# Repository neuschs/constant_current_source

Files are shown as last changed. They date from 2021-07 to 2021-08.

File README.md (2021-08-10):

# Constant Current Source
"Precise" Constant Current Source based on TI XTR110AG

# Main Components 

## Revision 0.1
### Arduino Nano
Simple Arduino for processing of the SCPI commands and coordinating the range switching.
### MCP3202
Two channel SPI 12 Bit ADC with external reference voltage.
### REF02
Reference voltage source used for internal "calibration" and as reference for arduino ADC and MCP3202

# Measurments
## Revision 0.1
### Stability over 2 Hours
Measured against reference voltage source REF02

#### Parameters:
- Duration: 2 Hours
- Frequency: 1s (approx.)
- Attentuatuation before LM324N: 8 (rough setting)
- LSB at ADC: approx 9,765mV (with Attentuation of 8)
- Internal Averaging Samples: 50

### Voltage A (Sense A):
| Value | Measurment |
| ---| --- |
|Standard Deviation| 1,456 mV |
|Maximum Value| 5.216500 V  |
|Minimum Value| 5.207500 V  |
|Mean Value| 5.213059 V  |
|25% of Counts| 5.212000 V  |
|50% of Coutns| 5.213200 V  |
|75% of Counts| 5.214200 V  |

### Boxplot and Histogram
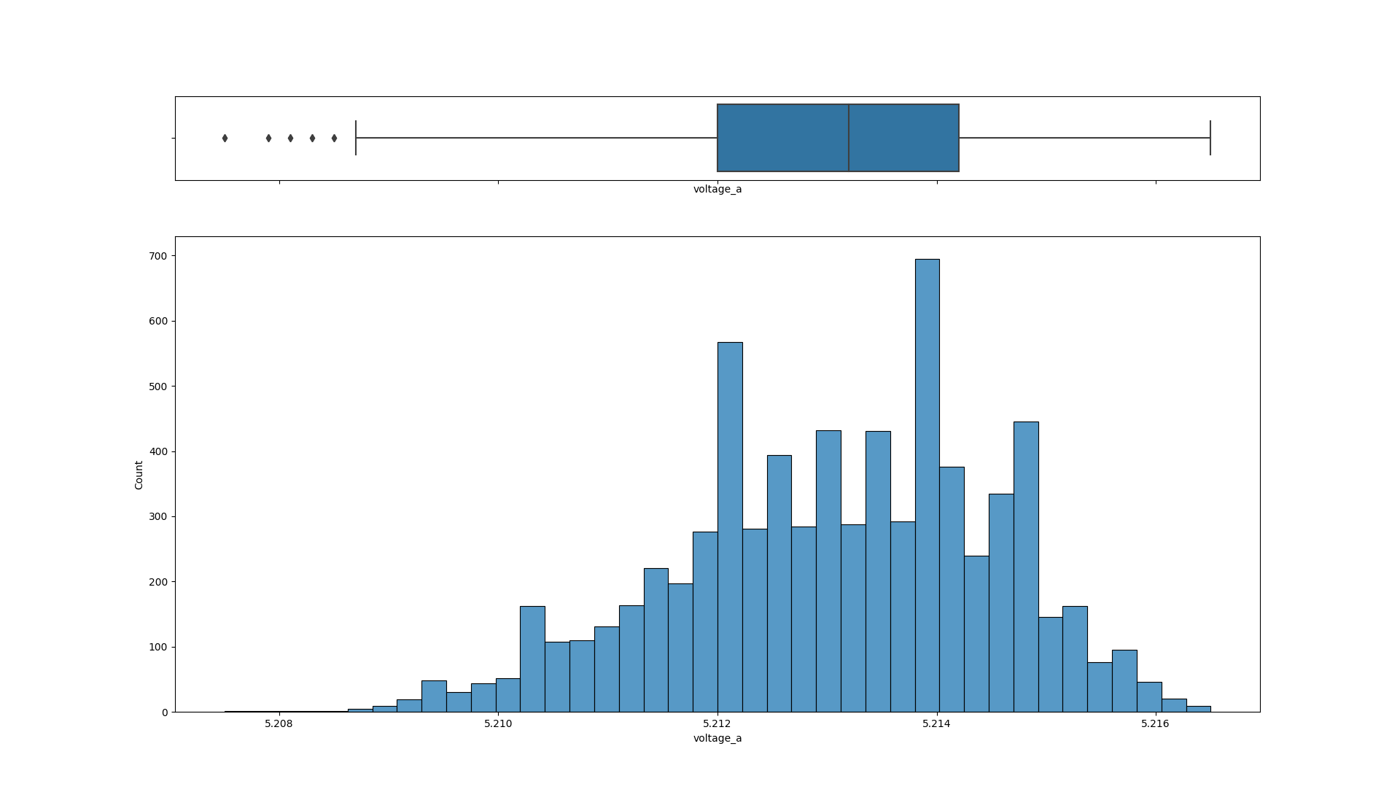
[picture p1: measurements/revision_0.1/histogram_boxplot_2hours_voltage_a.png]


### Voltage B (Sense B):
| Value | Measurment |
| ---| ---  |
|Standard Deviation| 411 uV |
|Maximum Value: |  5.150300 V  |
|Minimum Value: |  5.146000 V  |
|Mean Value: |  5.147937 V  |
|25% of Counts: |  5.147700 V  |
|50% of Coutns: |  5.147900 V  |
|75% of Counts: |  5.148100 V  |

### Boxplot and Histogram
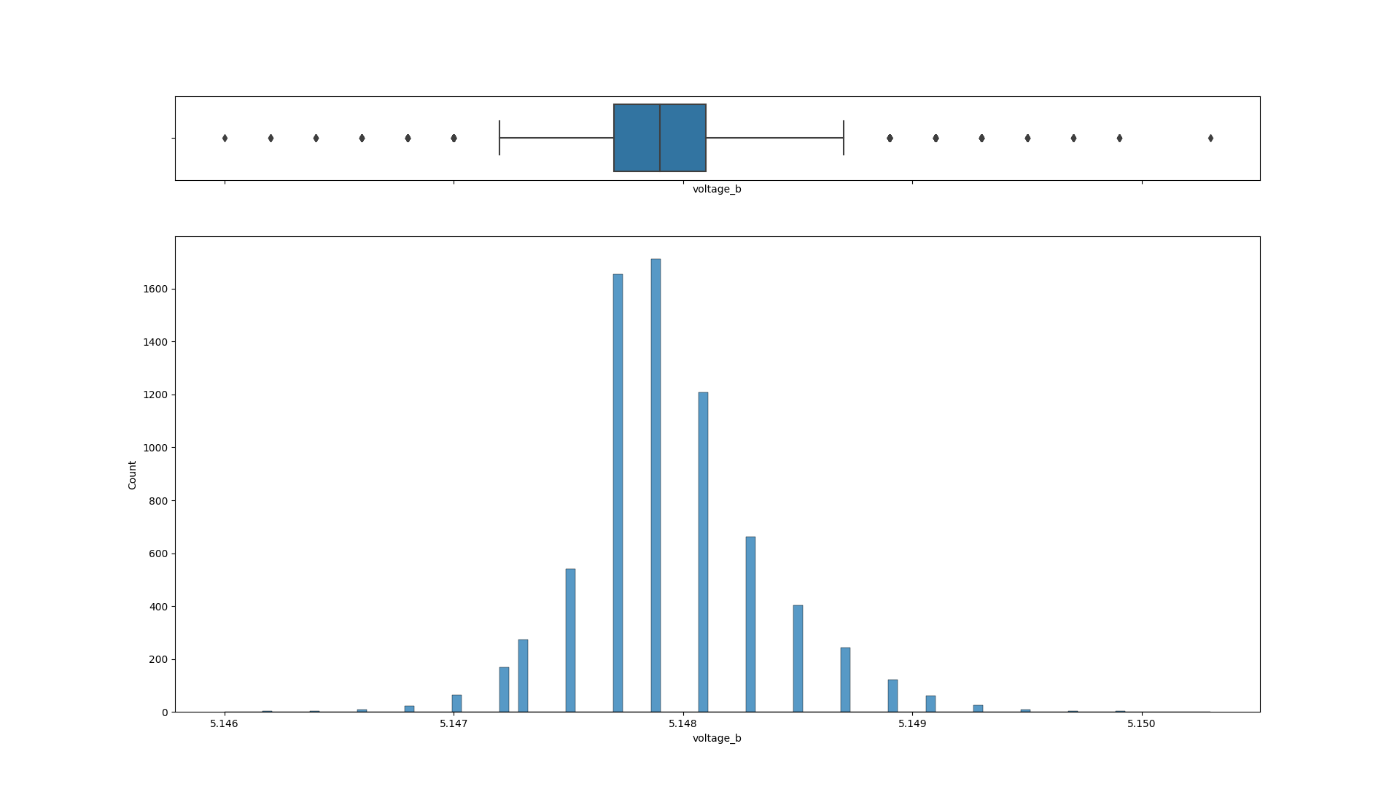
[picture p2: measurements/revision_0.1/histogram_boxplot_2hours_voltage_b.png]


### Overview over 2 Hours
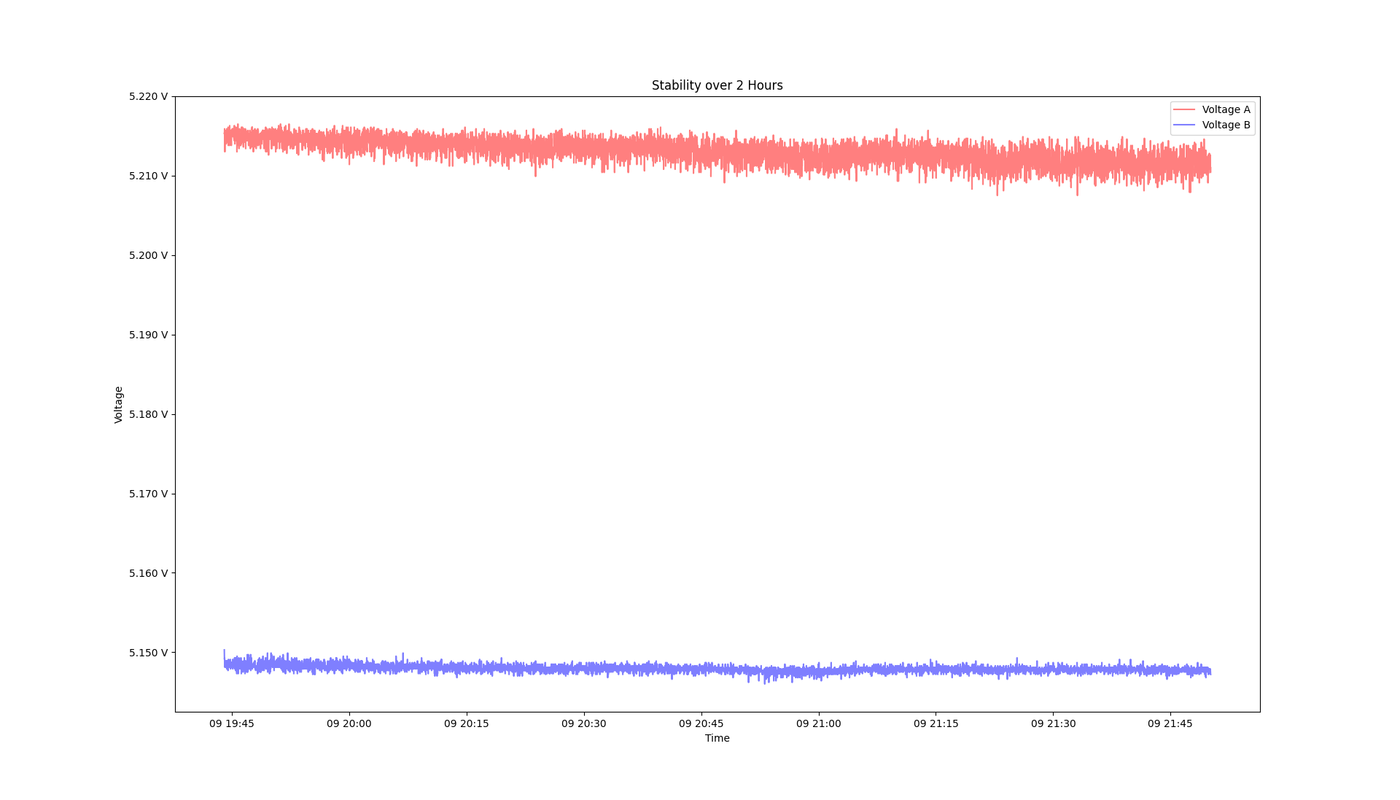
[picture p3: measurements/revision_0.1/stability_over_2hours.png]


### Result
> In some mysterious way, Sense A voltage measrument is way more bad than Sense B. Next measurment will be done over 24h with better shielding against the USB connection which is directly over the input attentuation voltage divider.

# Credits
Used Librarys:

[vrekrer/Vrekrer SCPI parser@0.4.1](https://github.com/Vrekrer/Vrekrer_scpi_parser)

[robtillaart/PCF8574@0.3.2](https://github.com/RobTillaart/PCF8574)

[mokolea/InputDebounce@1.6.0](https://github.com/Mokolea/InputDebounce)

[ouviksaha97/MCP3202@1.0.2](https://github.com/souviksaha97/MCP3202)

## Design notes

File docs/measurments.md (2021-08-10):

layout: page
title: "Measurments"
permalink: /measurments/

# Measurments
## Revision 0.1
### Stability over 2 Hours
Measured against reference voltage source REF02

#### Parameters:
- Duration: 2 Hours
- Frequency: 1s (approx.)
- Attentuatuation before LM324N: 8 (rough setting)
- LSB at ADC: approx 9,765mV (with Attentuation of 8)
- Internal Averaging Samples: 50

### Voltage A (Sense A):
| Value | Measurment |
| ---| --- |
|Standard Deviation| 1,456 mV |
|Maximum Value| 5.216500 V  |
|Minimum Value| 5.207500 V  |
|Mean Value| 5.213059 V  |
|25% of Counts| 5.212000 V  |
|50% of Coutns| 5.213200 V  |
|75% of Counts| 5.214200 V  |

### Boxplot and Histogram
![PIC][https://github.com/neuschs/constant_current_source/measurements/revision_0.1/histogram_boxplot_2hours_voltage_a.png]

### Voltage B (Sense B):
| Value | Measurment |
| ---| ---  |
|Standard Deviation| 411 uV |
|Maximum Value: |  5.150300 V  |
|Minimum Value: |  5.146000 V  |
|Mean Value: |  5.147937 V  |
|25% of Counts: |  5.147700 V  |
|50% of Coutns: |  5.147900 V  |
|75% of Counts: |  5.148100 V  |

### Boxplot and Histogram
hi

### Overview over 2 Hours
hi

### Result
> In some mysterious way, Sense A voltage measrument is way more bad than Sense B. Next measurment will be done over 24h with better shielding against the USB connection which is directly over the input attentuation voltage divider.

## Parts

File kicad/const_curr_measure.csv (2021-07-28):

ID | Bezeichner | Gehäuse | Stückzahl | Bezeichnung | Anbieter und Referenz
1 | J13 | PinHeader_1x05_P2.54mm_Vertical | 1 | Conn_01x05
2 | J5,J7 | PinHeader_1x03_P2.54mm_Vertical | 2 | Conn_01x03
3 | J3 | PinHeader_1x12_P2.54mm_Vertical | 1 | Conn_01x12
4 | U2 | DIP-8_W7.62mm_LongPads | 1 | MCP4821
5 | TP38,TP37,TP36,TP34,TP33,TP26,TP16,TP5,TP4,TP1,TP35,TP2,TP32,TP31,TP30,TP29,TP28,TP27,TP25,TP24,TP23,TP22,TP21,TP20,TP19,TP18,TP17,TP15,TP14,TP13,TP12,TP11,TP10,TP9,TP8,TP7,TP6,TP3 | TestPoint_THTPad_D2.5mm_Drill1.2mm | 38 | 1018.68
6 | U4 | DIP-8_W7.62mm_LongPads | 1 | MCP3202
7 | U3 | DIP-8_W7.62mm_LongPads | 1 | REF02CP
8 | RV1,R13,R4,R3 | Potentiometer_Piher_PT-6-V_Vertical | 4 | 10k
9 | C10,C8,C7,C6,C5,C2,C1 | C_Rect_L7.2mm_W3.0mm_P5.00mm_FKS2_FKP2_MKS2_MKP2 | 7 | 100nF
10 | R20 | R_Axial_DIN0207_L6.3mm_D2.5mm_P10.16mm_Horizontal | 1 | 4k7
11 | R19,R18,R10,R9 | R_Axial_DIN0207_L6.3mm_D2.5mm_P10.16mm_Horizontal | 4 | R
12 | R8,R12,R2 | R_Axial_DIN0207_L6.3mm_D2.5mm_P10.16mm_Horizontal | 3 | 10k
13 | D4,D3,D2,D1 | D_A-405_P10.16mm_Horizontal | 4 | D_Schottky
14 | A1 | Arduino_Nano | 1 | Arduino_Nano_v3.x
15 | J6,J8,J4,J2,J10,J9,J11 | 17263862 | 7 | 1-726386-2
16 | R7 | R_Axial_DIN0207_L6.3mm_D2.5mm_P10.16mm_Horizontal | 1 | 10
17 | R6 | R_Axial_DIN0207_L6.3mm_D2.5mm_P10.16mm_Horizontal | 1 | 1
18 | C4 | C_Rect_L7.2mm_W3.0mm_P5.00mm_FKS2_FKP2_MKS2_MKP2 | 1 | 1uF Tantal
19 | C3 | C_Rect_L7.2mm_W3.0mm_P5.00mm_FKS2_FKP2_MKS2_MKP2 | 1 | 10uF Tantal
20 | K4,K3,K1,K2 | 36SERIES-MINIATURE-PCB-RELAYS-10A | 4 | 36.11.9.005.4011
21 | R15,R5 | Potentiometer_Piher_PT-6-V_Vertical | 2 | 1k
22 | R14 | Potentiometer_Piher_PT-6-V_Vertical | 1 | 47k
23 | U6 | DIP-16_W7.62mm_LongPads | 1 | ULN2003
24 | H4,H3,H2,H1 | 638231 | 4 | 63823-1
25 | J12 | 09061152911_2 | 1 | 09061152911
26 | IC1 | CDIP774W53P254L2057H445Q16 | 1 | XTR110AG
27 | R17,R1,R11 | R_Axial_DIN0207_L6.3mm_D2.5mm_P10.16mm_Horizontal | 3 | 100k
28 | R16 | R_Axial_DIN0207_L6.3mm_D2.5mm_P10.16mm_Horizontal | 1 | 82k
29 | C9 | C_Disc_D5.0mm_W2.5mm_P5.00mm | 1 | 100nF
30 | U5 | DIP-16_W7.62mm_LongPads | 1 | PCF8574
31 | U1 | DIP-14_W7.62mm_LongPads | 1 | LM324
32 | J1 | PinHeader_2x02_P2.54mm_Vertical | 1 | Conn_02x02_Counter_Clockwise

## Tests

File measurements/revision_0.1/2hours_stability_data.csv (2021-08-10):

time | voltage_a | voltage_b
2021-08-09 19:44:02.686931 | 5.2153 | 5.1503
2021-08-09 19:44:03.738297 | 5.2153 | 5.1491
2021-08-09 19:44:04.789710 | 5.2159 | 5.1493
2021-08-09 19:44:05.840950 | 5.2151 | 5.1489
2021-08-09 19:44:06.892429 | 5.213 | 5.1481
2021-08-09 19:44:07.944663 | 5.2157 | 5.1485
2021-08-09 19:44:08.996051 | 5.2142 | 5.1487
2021-08-09 19:44:10.047480 | 5.2144 | 5.1489
2021-08-09 19:44:11.098875 | 5.2147 | 5.1483
2021-08-09 19:44:12.151008 | 5.2153 | 5.1481
2021-08-09 19:44:13.202452 | 5.2153 | 5.1489
2021-08-09 19:44:14.253629 | 5.2147 | 5.1487
2021-08-09 19:44:15.305876 | 5.2157 | 5.1481
2021-08-09 19:44:16.357240 | 5.2146 | 5.1485
2021-08-09 19:44:17.408811 | 5.214 | 5.1483
2021-08-09 19:44:18.460804 | 5.2149 | 5.1483
2021-08-09 19:44:19.512178 | 5.2155 | 5.1489
2021-08-09 19:44:20.563529 | 5.2151 | 5.1483
2021-08-09 19:44:21.615037 | 5.2159 | 5.1479
2021-08-09 19:44:22.667254 | 5.2153 | 5.1489
2021-08-09 19:44:23.718610 | 5.2146 | 5.1485
2021-08-09 19:44:24.747614 | 5.2157 | 5.1485
2021-08-09 19:44:25.798987 | 5.2149 | 5.1483
2021-08-09 19:44:26.850393 | 5.2153 | 5.1479
2021-08-09 19:44:27.902583 | 5.2144 | 5.1489
2021-08-09 19:44:28.953960 | 5.2142 | 5.1485
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

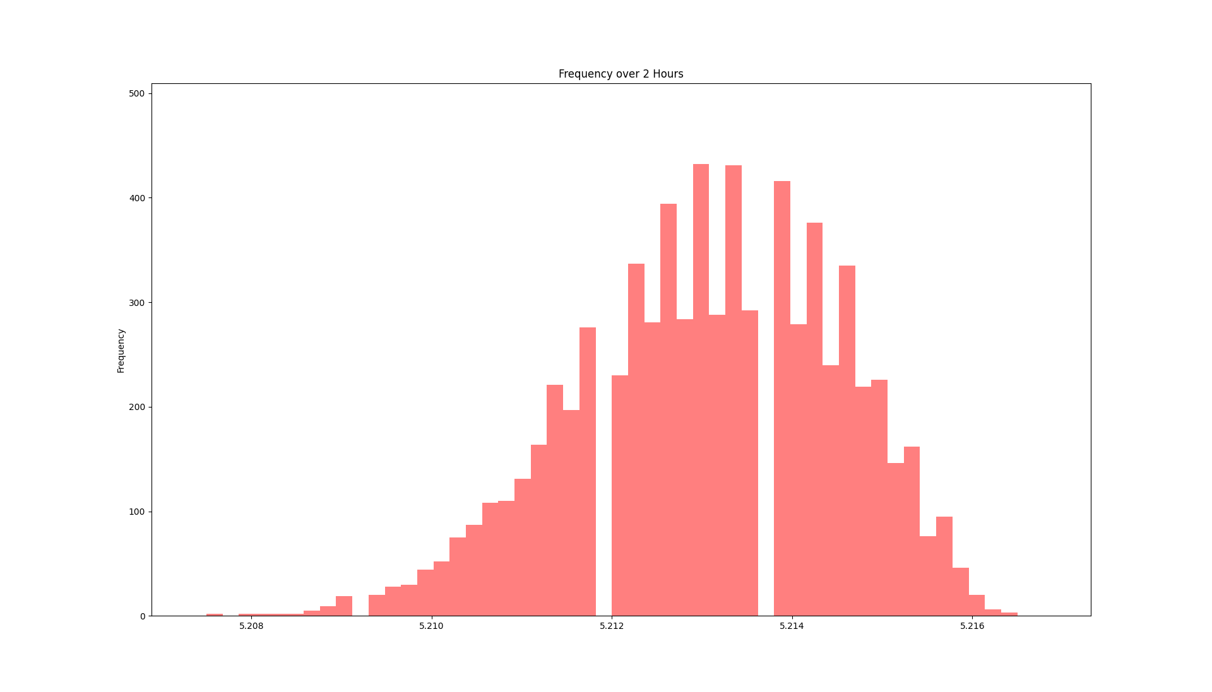
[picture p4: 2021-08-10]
measurements/revision_0.1/frequeny_2hours_voltage_a.png

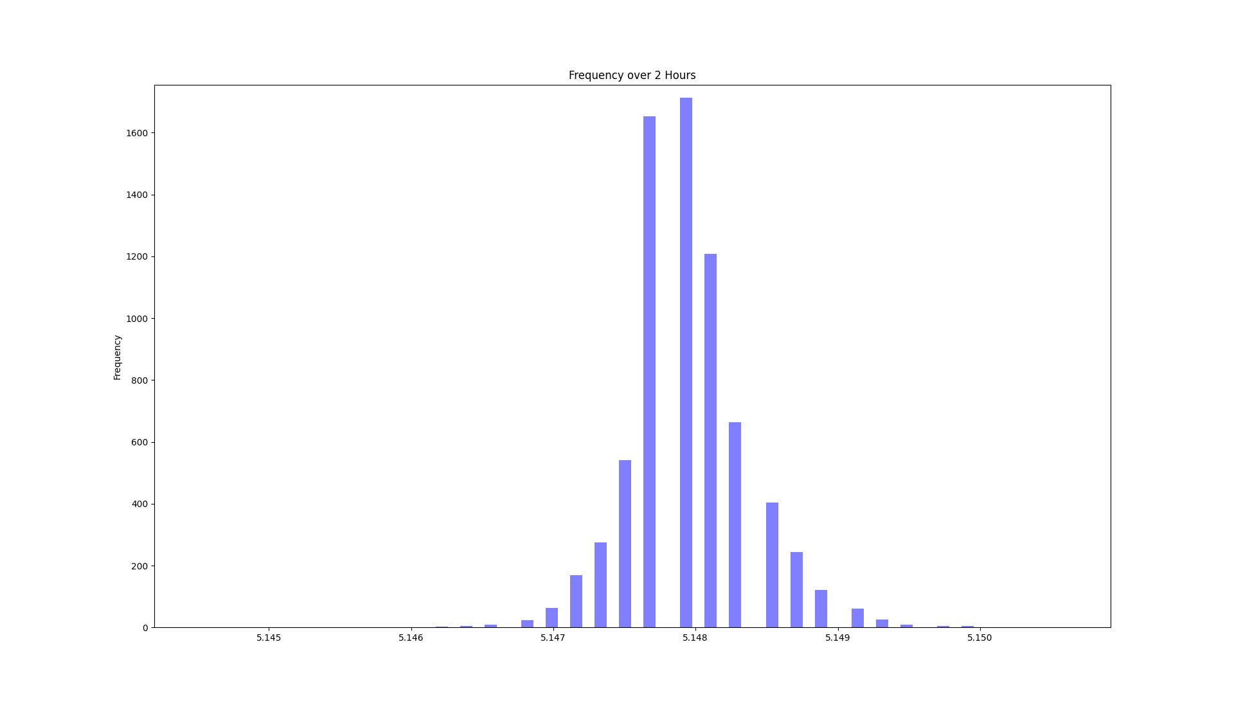
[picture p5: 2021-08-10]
measurements/revision_0.1/frequeny_2hours_voltage_b.png

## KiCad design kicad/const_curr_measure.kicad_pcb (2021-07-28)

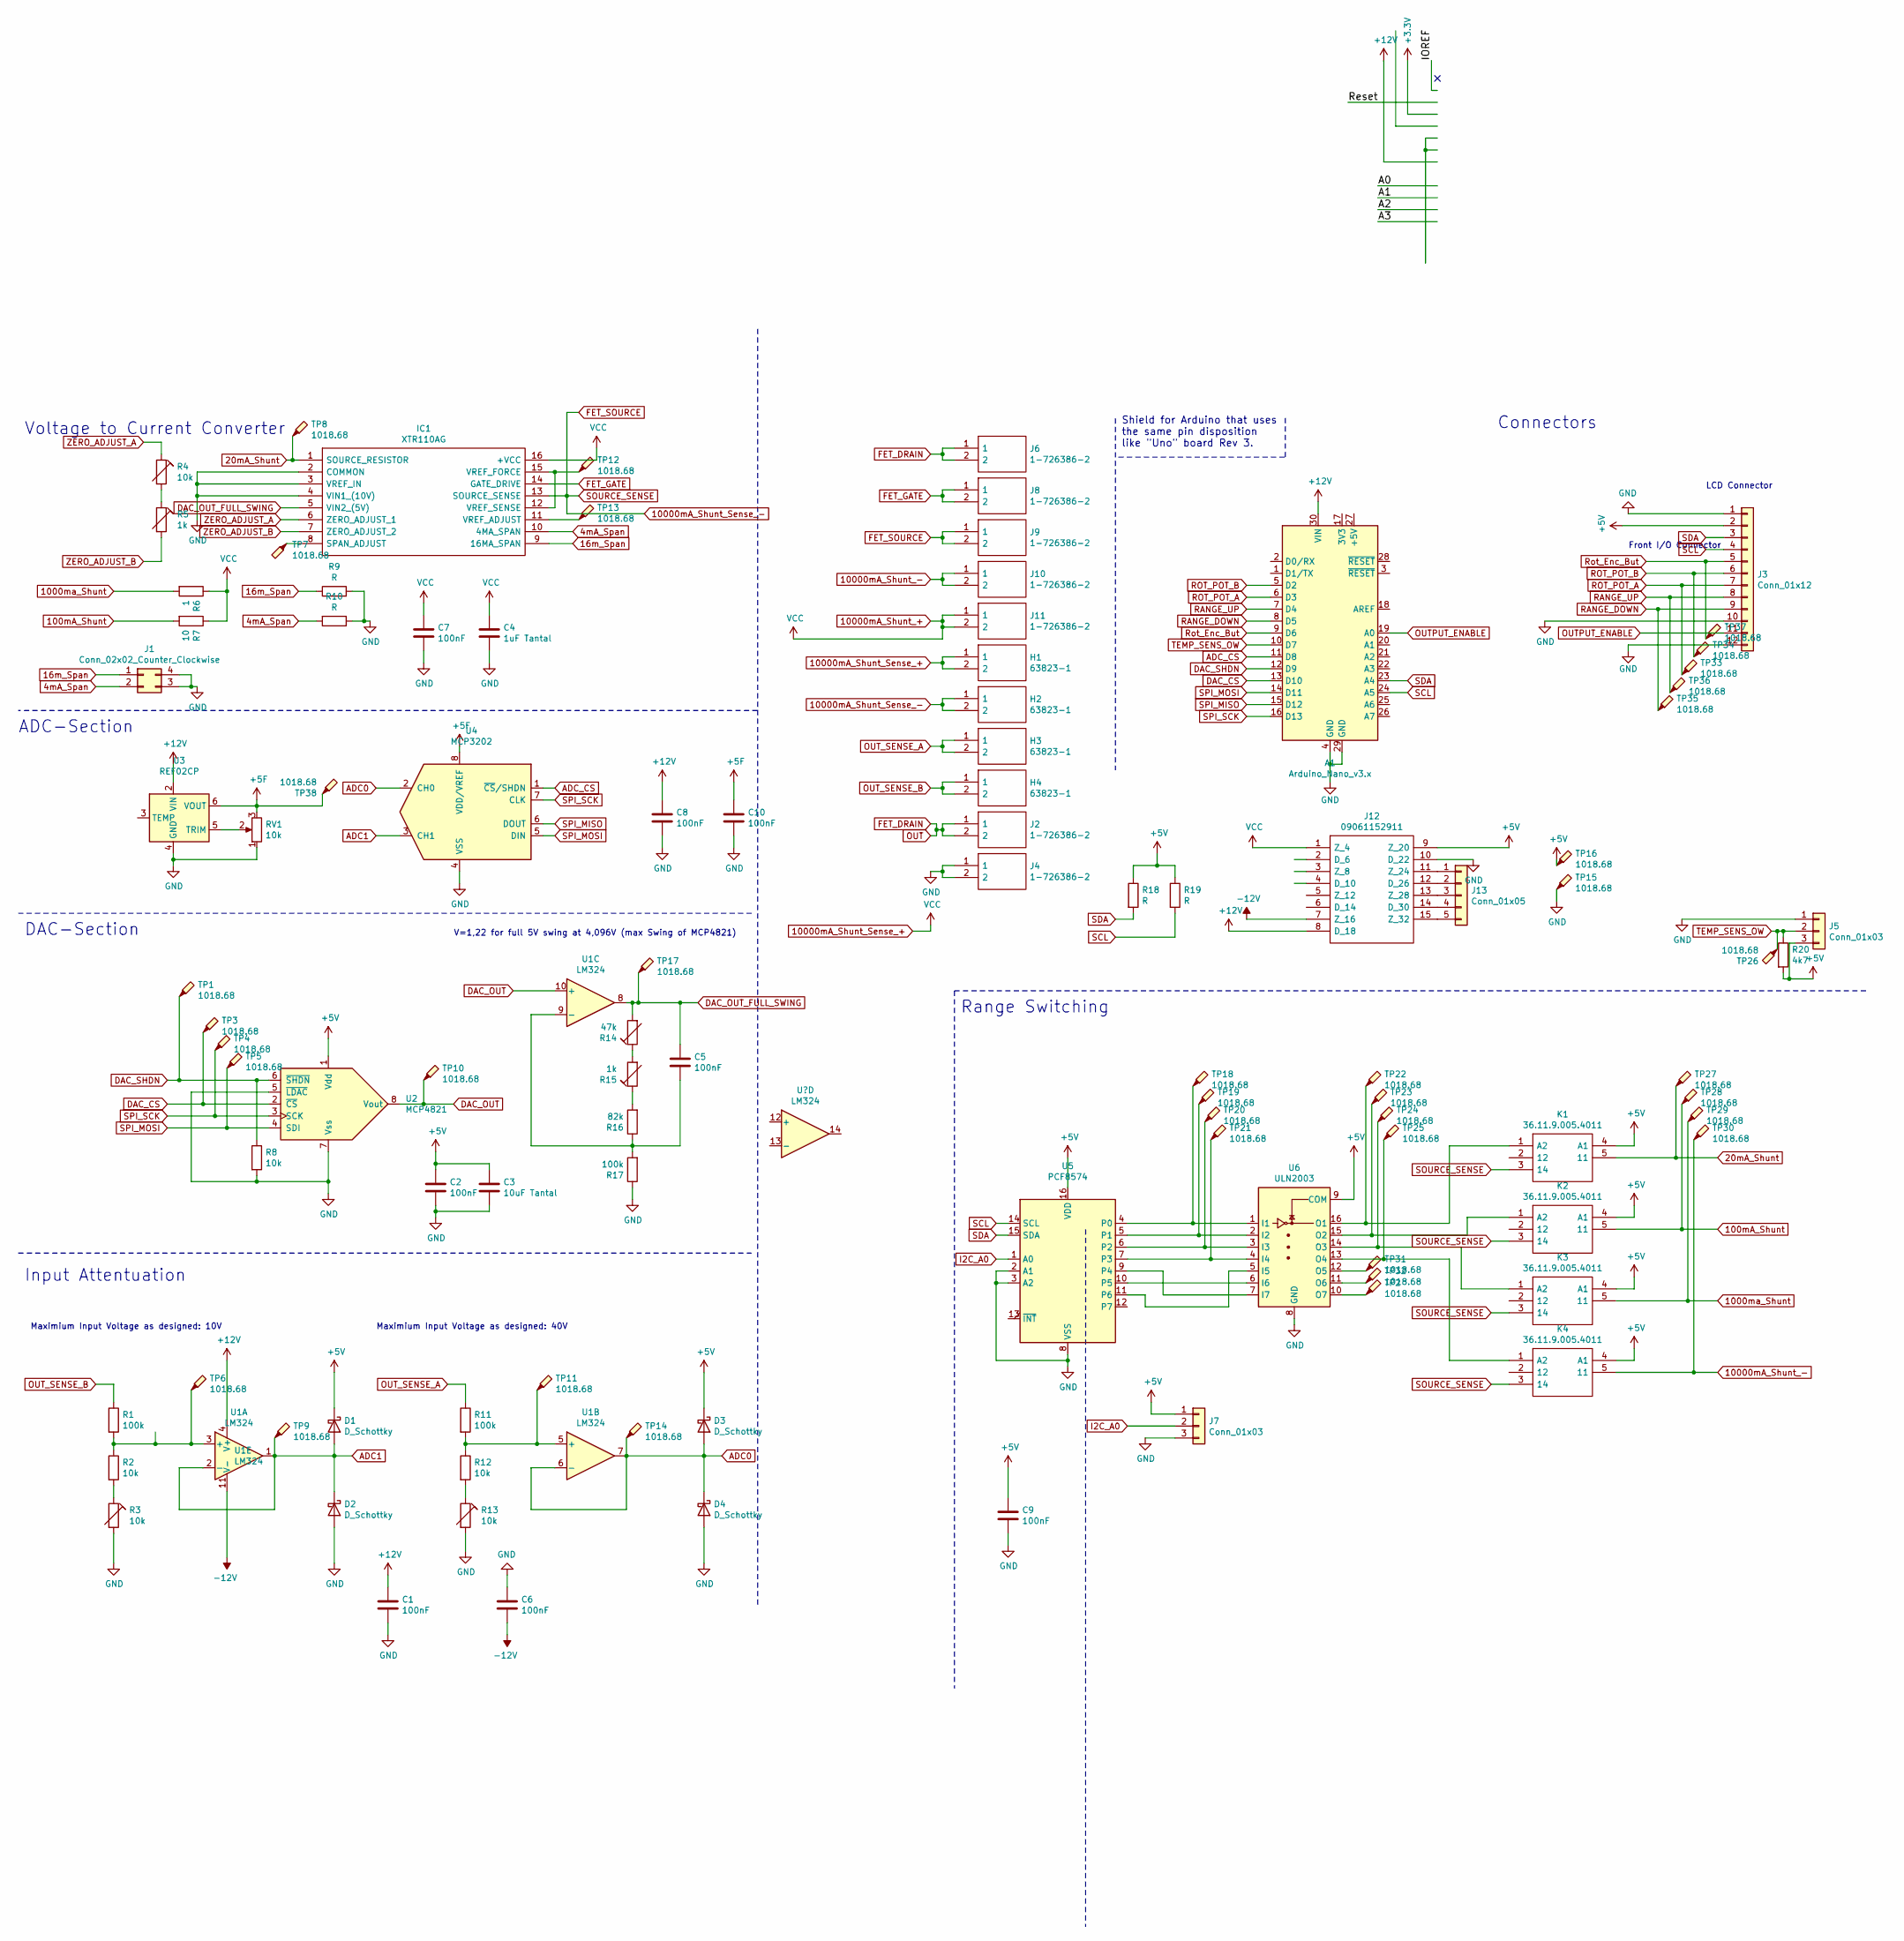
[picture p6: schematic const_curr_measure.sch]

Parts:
A1: Arduino_Nano_v3.x; Arduino_Nano
C1, C2, C5, C6, C7, C8, C10: 100nF; C_Rect_L7.2mm_W3.0mm_P5.00mm_FKS2_FKP2_MKS2_MKP2
C3: 10uF Tantal; C_Rect_L7.2mm_W3.0mm_P5.00mm_FKS2_FKP2_MKS2_MKP2
C4: 1uF Tantal; C_Rect_L7.2mm_W3.0mm_P5.00mm_FKS2_FKP2_MKS2_MKP2
C9: 100nF; C_Disc_D5.0mm_W2.5mm_P5.00mm
D1, D2, D3, D4: D_Schottky; D_A-405_P10.16mm_Horizontal
H1, H2, H3, H4: 63823-1; 638231; Mouser Part Number 571-638231
IC1: XTR110AG; CDIP774W53P254L2057H445Q16; Mouser Part Number 595-XTR110AG
J1: Conn_02x02_Counter_Clockwise; PinHeader_2x02_P2.54mm_Vertical
J2, J4, J6, J8, J9, J10, J11: 1-726386-2; 17263862; Mouser Part Number 571-1-726386-2
J3: Conn_01x12; PinHeader_1x12_P2.54mm_Vertical
J5, J7: Conn_01x03; PinHeader_1x03_P2.54mm_Vertical
J12: 09061152911; 09061152911_2; Manufacturer_Part_Number 09061152911; Mouser Part Number 617-09-06-115-2911
J13: Conn_01x05; PinHeader_1x05_P2.54mm_Vertical
K1, K2, K3, K4: 36.11.9.005.4011; 36SERIES-MINIATURE-PCB-RELAYS-10A; Manufacturer_Part_Number 36.11.9.005.4011
R1, R11, R17: 100k; R_Axial_DIN0207_L6.3mm_D2.5mm_P10.16mm_Horizontal
R2, R8, R12: 10k; R_Axial_DIN0207_L6.3mm_D2.5mm_P10.16mm_Horizontal
R3, R4, R13: 10k; Potentiometer_Piher_PT-6-V_Vertical
R5, R15: 1k; Potentiometer_Piher_PT-6-V_Vertical
R6: 1; R_Axial_DIN0207_L6.3mm_D2.5mm_P10.16mm_Horizontal
R7: 10; R_Axial_DIN0207_L6.3mm_D2.5mm_P10.16mm_Horizontal
R9, R10, R18, R19: R; R_Axial_DIN0207_L6.3mm_D2.5mm_P10.16mm_Horizontal
R14: 47k; Potentiometer_Piher_PT-6-V_Vertical
R16: 82k; R_Axial_DIN0207_L6.3mm_D2.5mm_P10.16mm_Horizontal
R20: 4k7; R_Axial_DIN0207_L6.3mm_D2.5mm_P10.16mm_Horizontal
RV1: 10k; Potentiometer_Piher_PT-6-V_Vertical
TP1, TP2, TP3, TP4, TP5, TP6, TP7, TP8, TP9, TP10, TP11, TP12, TP13, TP14, TP15, TP16, TP17, TP18, TP19, TP20, TP21, TP22, TP23, TP24, TP25, TP26, TP27, TP28, TP29, TP30, TP31, TP32, TP33, TP34, TP35, TP36, TP37, TP38: 1018.68; TestPoint_THTPad_D2.5mm_Drill1.2mm
U1: LM324; DIP-14_W7.62mm_LongPads
U2: MCP4821; DIP-8_W7.62mm_LongPads
U3: REF02CP; DIP-8_W7.62mm_LongPads
U4: MCP3202; DIP-8_W7.62mm_LongPads
U5: PCF8574; DIP-16_W7.62mm_LongPads
U6: ULN2003; DIP-16_W7.62mm_LongPads

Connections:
4mA_Span: IC1.10 (4MA_SPAN), J1.2, R10.2
16m_Span: IC1.9 (16MA_SPAN), J1.1, R9.1
20mA_Shunt: IC1.1 (SOURCE_RESISTOR), K1.5 (11), TP8.1, TP27.1
100mA_Shunt: K2.5 (11), R7.2, TP28.1
1000ma_Shunt: K3.5 (11), R6.2, TP29.1
10000mA_Shunt_+: C4.1, C7.1, H1.1, H1.2, IC1.16 (+VCC), J11.1, J11.2, J12.1 (Z_4), R6.1, R7.1
10000mA_Shunt_-: J10.1, J10.2, K4.5 (11), TP30.1
10000mA_Shunt_Sense_-: H2.1, H2.2, IC1.13 (SOURCE_SENSE), J9.1, J9.2, K1.3 (14), K2.3 (14), K3.3 (14), K4.3 (14)
+5F: C10.1, RV1.3, TP38.1, U3.6 (VOUT), U4.8 (VDD/VREF)
+5V: C2.1, C3.1, C9.1, D1.1 (K), D3.1 (K), J3.2, J5.3, J7.1, J12.9 (Z_20), K1.4 (A1), K2.4 (A1), K3.4 (A1), K4.4 (A1), R18.1, R19.1, R20.2, TP16.1, U2.1 (Vdd), U5.16 (VDD), U6.9 (COM)
+12V: A1.30 (VIN), C1.1, C8.1, J12.8 (D_18), U1.4 (V+), U3.2 (VIN)
-12V: C6.2, J12.7 (Z_16), U1.11 (V-)
ADC0: D3.2 (A), D4.1 (K), TP14.1, U1.6 (-), U1.7, U4.2 (CH0)
ADC1: D1.2 (A), D2.1 (K), TP9.1, U1.1, U1.2 (-), U4.3 (CH1)
ADC_CS: A1.11 (D8), U4.1 (~CS~/SHDN)
DAC_CS: A1.13 (D10), TP3.1, U2.2 (~CS)
DAC_OUT: TP10.1, U1.10 (+), U2.8 (Vout)
DAC_OUT_FULL_SWING: C5.1, IC1.5 (VIN2_(5V)), R14.2, TP17.1, U1.8
DAC_SHDN: A1.12 (D9), R8.1, TP1.1, U2.6 (~SHDN)
FET_DRAIN: J2.1, J2.2, J6.1, J6.2
FET_GATE: IC1.14 (GATE_DRIVE), J8.1, J8.2
GND: A1.4 (GND), A1.29 (GND), C1.2, C2.2, C3.2, C4.2, C6.1, C7.2, C8.2, C9.2, C10.2, D2.2 (A), D4.2 (A), IC1.2 (COMMON), IC1.3 (VREF_IN), IC1.4 (VIN1_(10V)), J1.3, J1.4, J3.1, J3.10, J3.12, J4.1, J4.2, J5.1, J7.3, J12.10 (D_22), R3.2, R8.2, R9.2, R10.1, R13.2, R17.1, RV1.1, TP15.1, U2.5 (~LDAC), U2.7 (Vss), U3.4 (GND), U4.4 (VSS), U5.2 (A1), U5.3 (A2), U5.8 (VSS), U6.8 (GND)
I2C_A0: J7.2, U5.1 (A0)
unnamed: C5.2, R16.1, R17.2, U1.9 (-)
unnamed: IC1.8 (SPAN_ADJUST), TP7.1
unnamed: IC1.11 (VREF_ADJUST), TP13.1
unnamed: IC1.12 (VREF_SENSE), IC1.15 (VREF_FORCE), TP12.1
unnamed: J12.11 (Z_24), J13.1
unnamed: J12.12 (D_26), J13.2
unnamed: J12.13 (Z_28), J13.3
unnamed: J12.14 (D_30), J13.4
unnamed: J12.15 (Z_32), J13.5
unnamed: K1.1 (A2), TP22.1, U6.16 (O1)
unnamed: K2.1 (A2), TP23.1, U6.15 (O2)
unnamed: K3.1 (A2), TP24.1, U6.14 (O3)
unnamed: K4.1 (A2), TP25.1, U6.13 (O4)
unnamed: R1.2, R2.1, TP6.1, U1.3 (+)
unnamed: R2.2, R3.1
unnamed: R4.2, R5.1
unnamed: R11.2, R12.1, TP11.1, U1.5 (+)
unnamed: R12.2, R13.1
unnamed: R14.1, R15.2
unnamed: R15.1, R16.2
unnamed: RV1.2, U3.5 (TRIM)
unnamed: TP2.1, U6.10 (O7)
unnamed: TP18.1, U5.4 (P0), U6.1 (I1)
unnamed: TP19.1, U5.5 (P1), U6.2 (I2)
unnamed: TP20.1, U5.6 (P2), U6.3 (I3)
unnamed: TP21.1, U5.7 (P3), U6.4 (I4)
unnamed: TP31.1, U6.12 (O5)
unnamed: TP32.1, U6.11 (O6)
unnamed: U5.9 (P4), U6.7 (I7)
unnamed: U5.10 (P5), U6.6 (I6)
unnamed: U5.11 (P6), U6.5 (I5)
OUTPUT_ENABLE: A1.19 (A0), J3.11
OUT_SENSE_A: H3.1, H3.2, R11.1
OUT_SENSE_B: H4.1, H4.2, R1.1
RANGE_DOWN: A1.8 (D5), J3.9, TP35.1
RANGE_UP: A1.7 (D4), J3.8, TP36.1
ROT_POT_A: A1.6 (D3), J3.7, TP33.1
ROT_POT_B: A1.5 (D2), J3.6, TP34.1
Rot_Enc_But: A1.9 (D6), J3.5, TP37.1
SCL: A1.24 (A5), J3.4, R19.2, U5.14 (SCL)
SDA: A1.23 (A4), J3.3, R18.2, U5.15 (SDA)
SPI_MISO: A1.15 (D12), U4.6 (DOUT)
SPI_MOSI: A1.14 (D11), TP5.1, U2.4 (SDI), U4.5 (DIN)
SPI_SCK: A1.16 (D13), TP4.1, U2.3 (SCK), U4.7 (CLK)
TEMP_SENS_OW: A1.10 (D7), J5.2, R20.1, TP26.1
ZERO_ADJUST_A: IC1.6 (ZERO_ADJUST_1), R4.1
ZERO_ADJUST_B: IC1.7 (ZERO_ADJUST_2), R5.2

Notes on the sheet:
Shield for Arduino that uses the same pin disposition like "Uno" board Rev 3.
Maximium Input Voltage as designed: 10V
Maximium Input Voltage as designed: 40V
Front I/O Connector
Input Attentuation
DAC-Section
Range Switching
Voltage to Current Converter
Connectors
V=1,22 for full 5V swing at 4,096V (max Swing of MCP4821)
LCD Connector
ADC-Section

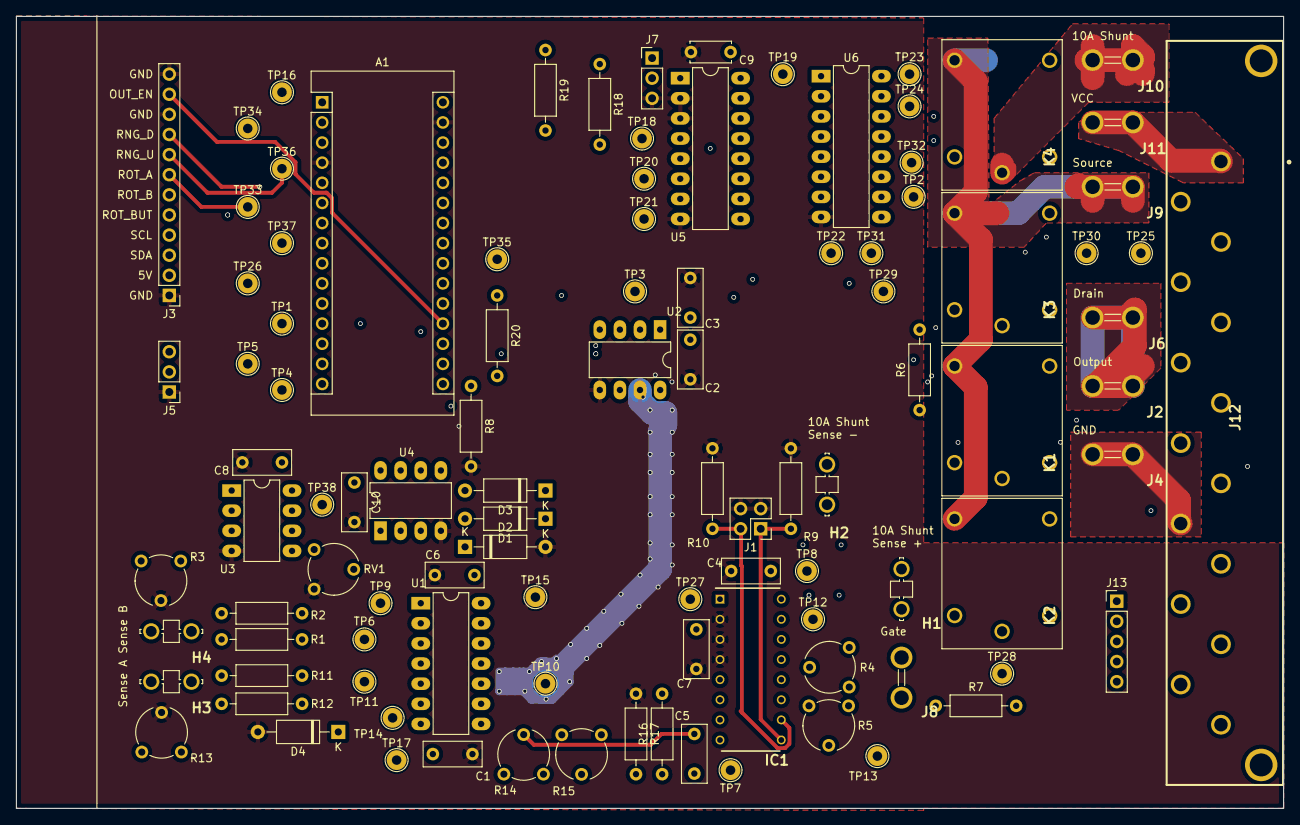
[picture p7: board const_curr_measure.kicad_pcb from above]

Board: 4 copper layers, 160.0 x 100.0 mm, 102 parts (0 on the bottom side), 70 nets.

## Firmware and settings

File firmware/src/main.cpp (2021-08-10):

#include <Arduino.h>
#include "Main.hpp"
#include <SPI.h>
#include "PCF8574.h"
#include "InputDebounce.h"
#include "MCP3202.h"

/* can deactivate for less ram / flash consumption */
#define __SCPI__

#ifdef __SCPI__
/* got more commands than the libraray supports by default */
#include "Vrekrer_scpi_parser.h"
#include "scpi_handler.hpp"
#endif

/*
   Global Variables
*/
/* IO Expander PCF8574 Object */
PCF8574 IO_Expander(PCF8574_ADDRESS);

/* ADC MCP3202 */
MCP3202 _adc;

/* SCPI Parser Global Object */
#ifdef __SCPI__
SCPI_Parser SCPI;
#endif __SCPI__

/* global ressource pointer */
static RSC_STRUCT_T tRscStruct = {0};
RSC_STRUCT_T *ptRscStruct = &tRscStruct;

/* debounced pin objects */
static InputDebounce RangeUpButton;
static InputDebounce RangeDownButton;

int setDACOutput(bool gain, bool enable, uint16_t val)
{
  MCP4821_COMMAND_T tCommandBuffer;
  uint16_t buffer = 0;

  /* fill command struct */
  tCommandBuffer.gain = gain;
  tCommandBuffer.value = val;
  tCommandBuffer.shdn = enable;

  /* copy to uint16_t (aka convert) */
  memcpy(&buffer, &tCommandBuffer, sizeof(MCP4821_COMMAND_T));

  /* byteorder in struct is wrong so switch high byte and low byte */
  buffer = __builtin_bswap16((uint16_t)buffer);

  /* drive chip select low */
  PORTB &= ~DAC_MCP4821_CS_Mask;

  /* transfer the two bytes via spi */
  SPI.transfer(&buffer, sizeof(MCP4821_COMMAND_T));

  /* drive chip select high */
  PORTB |= DAC_MCP4821_CS_Mask;

}



/*  my own map with double precisision */
float _map(float x, float in_min, float in_max, float out_min, float out_max)
{
  return (x - in_min) * (out_max - out_min) / (in_max - in_min) + out_min;
}

#ifdef __SCPI__
void scpi_self_test_cb(SCPI_C commands, SCPI_P parameters, Stream& interface)
{
  // executes self test
  uint16_t usDACOutMeas = 0;
  double fRealVoltage = 0;

  /* activate dac */
  PORTB |= DAC_MCP4821_SHDN_Mask;

  interface.println(F("Test DAC Output:"));
  setDACOutput(DAC_MCP4821_GAIN_2, true, DAC_MAX_COUNT);
  interface.print(F("Set DAC Out (V):\t")); interface.println(DAC_MAX_VAL);
  usDACOutMeas = analogRead(DAC_OUT_READBACK);
  interface.print(F("Read back (V):\t"));
  fRealVoltage = _map(usDACOutMeas, 0, ARDUINO_MAX_ADC_IN, 0.0, ARDUINO_REF_VOLTAGE);

  interface.println(fRealVoltage);
  interface.print(F("Upper Limit: ")); interface.print(DAC_MAX_TOL_VAL); interface.print(F(" / Lower Limit:")); interface.println(DAC_MIN_TOL_VAL);
  if ((fRealVoltage <= DAC_MAX_TOL_VAL) && (fRealVoltage >= DAC_MIN_TOL_VAL))
  {
    ptRscStruct->gusError &= ~ERROR_DAC_OUT_Mask;
    interface.println(F("Test Pass"));
  }
  else
  {
    ptRscStruct->gusError |= ERROR_DAC_OUT_Mask;
    interface.println(F("Test Fail"));
  }
  interface.println(F(""));
  interface.println(F("Test DAC OP-Amp Output (DAC-Out * 1.22):"));
  interface.print(F("Set DAC Out (V):\t")); interface.println(DAC_MAX_VAL);
  usDACOutMeas = analogRead(DAC_OUT_FS_READBACK);
  interface.print(F("Read back (V):\t"));
  fRealVoltage = _map(usDACOutMeas, 0, ARDUINO_MAX_ADC_IN, 0.0, ARDUINO_REF_VOLTAGE);

  interface.println(fRealVoltage);
  interface.print(F("Upper Limit: ")); interface.print(DAC_FS_MAX_TOL_VAL); interface.print(F(" / Lower Limit:")); interface.println(DAC_FS_MIN_TOL_VAL);
  if ((fRealVoltage <= DAC_FS_MAX_TOL_VAL) && (fRealVoltage >= DAC_FS_MIN_TOL_VAL))
  {
    ptRscStruct->gusError &= ~ERROR_DAC_OUT_FS_Mask;
    interface.println(F("Test Pass"));
  }
  else
  {
    ptRscStruct->gusError |= ERROR_DAC_OUT_FS_Mask;
    interface.println("Test Fail");
  }

  PORTB &= ~DAC_MCP4821_SHDN_Mask;
}
#endif

void range_up_down_btn_released_cb(uint8_t pinIn)
{
  if(pinIn == BUTTON_RANGE_UP_PIN)
  {

  }
  else if(pinIn == BUTTON_RANGE_DOWN_PIN)
  {

  }
}

void setup()
{
  /* debounce callback registration */
  RangeUpButton.registerCallbacks(NULL, range_up_down_btn_released_cb, NULL, NULL);
  RangeDownButton.registerCallbacks(NULL, range_up_down_btn_released_cb, NULL, NULL);

  /* debounce pin initialization */
  RangeUpButton.setup(BUTTON_RANGE_UP_PIN, BUTTON_DEBOUNCE_DELAY, InputDebounce::PIM_INT_PULL_UP_RES);
  RangeDownButton.setup(BUTTON_RANGE_DOWN_PIN, BUTTON_DEBOUNCE_DELAY, InputDebounce::PIM_INT_PULL_UP_RES);

  /* initialize mcp3202 */
  _adc = MCP3202(ADC_MCP3202_CS);
  _adc.begin();

  /* set default range to 20ma */
  ptRscStruct->range = RELAY_20mA_Mask;

  /* initialization routines for DAC */
  /* set DAC_MCP4821_CS pin mode to output */
  DDRB |= DAC_MCP4821_CS_Mask | DAC_MCP4821_SHDN_Mask;

  /* set chip select for DAC to high */
  /* set DAC SHDN (Shutdown) to low to deactivate the DAC output */
  PORTB |= DAC_MCP4821_CS_Mask;
  PORTB &= ~DAC_MCP4821_SHDN_Mask;

  /* use external analog reference voltage (REF02CP) */
  analogReference(EXTERNAL);

  /* Initialization of serial connection to host */
  Serial.begin(BAUD_RATE);

  /* spi setup */
  SPI.begin();
  SPI.setClockDivider(SPI_CLOCK_DIV2);

#ifdef __SCPI__
  /* scpi request setup */
  SCPI.RegisterCommand(SCPI_IDENTIFY_CMD, &scpi_identify_cb);
  SCPI.RegisterCommand(SCPI_ERROR_READ_CMD, &scpi_error_read_cb);
  SCPI.RegisterCommand(SCPI_SELF_TEST_CMD, &scpi_self_test_cb);
  /* range swichting command registrations */
  SCPI.RegisterCommand(SCPI_RANGE_CMD_REQ, &scpi_get_range);
  SCPI.RegisterCommand(SCPI_RANGE_20mA, &scpi_select_range_20ma);
  SCPI.RegisterCommand(SCPI_RANGE_100mA, &scpi_select_range_100ma);
  SCPI.RegisterCommand(SCPI_RANGE_1000mA, &scpi_select_range_1000ma);
  SCPI.RegisterCommand(SCPI_RANGE_10000mA, &scpi_select_range_10000ma);
  /* temperature readouts */
  SCPI.RegisterCommand(SCPI_TEMP_INTERNAL, &scpi_internal_temp);
  SCPI.RegisterCommand(SCPI_TEMP_MOSFET, &scpi_mosfet_temp);
  SCPI.RegisterCommand(SCPI_TEMP_REF, &scpi_reference_temp);
  /* voltage reading */
  SCPI.RegisterCommand(SCPI_VOLT_SENSE_A, &scpi_get_voltage_a);
  SCPI.RegisterCommand(SCPI_VOLT_SENSE_B, &scpi_get_voltage_b);
  SCPI.RegisterCommand(SCPI_VOLT_ABSOLUTE, &scpi_get_absolute_voltage);
  /* current setting */
  SCPI.RegisterCommand(SCPI_CURR_SET, &scpi_set_current);
  SCPI.RegisterCommand(SCPI_CURR_GET, &scpi_get_current);
#endif

  /* start communication with PCF8574 */
  if (!IO_Expander.begin())
  {
    ptRscStruct->gusError |= ERROR_I2C_Mask;
  }
  else
  {
    if (!IO_Expander.isConnected())
    {
      ptRscStruct->gusError |= ERROR_I2C_Mask;
    }
    else
    {
      /* reset (seto to low) all outputs */
      IO_Expander.write8(0xFF);
    }
  }

  /* execute self test */
  //self_test();
}

void read_temperature()
{
  /* temperature of reference voltage */
  double tempRaw = 0;
  /* read value of adc */
  uint16_t usRefTempRaw = analogRead(TEMP_REFERENCE_VOLT_PIN);
  /* map analog reading to reference voltage in millivolt */
  tempRaw = _map(usRefTempRaw, 0, ARDUINO_MAX_ADC_IN, 0, ARDUINO_REF_VOLTAGE*1000);
  /* calculate real voltage at ref (divide by real op amp gain) */
  tempRaw = tempRaw / ((TEMP_R_FEEDBACK / TEMP_R_IN) + 1);
  /* calculate tempreature in degree above TEMP_REF_BASE_TEMP° or below */
  tempRaw = ((tempRaw - TEMP_REF_BASE_MVOLT) / TEMP_REF_TEMP_COEF);
  /* offeset value by TEMP_REF_BASE_TEMP */
  tempRaw = tempRaw + TEMP_REF_BASE_TEMP;

  ptRscStruct->referenceTemp = tempRaw;
}


void read_input_voltage()
{
  static uint8_t counter = 0;
  static float values_a;
  static float values_b;
  static float values_abs;

  float fAbsoluteValue;
  float usRawChannelA = _adc.readChannel(ADC_CHANNEL_SENSE_A);
  float usRawChannelB = _adc.readChannel(ADC_CHANNEL_SENSE_B);

  /* convert 0 .. ADC_MAX_COUNT to 0 .. ADC_MCP3202_REF_V */
  usRawChannelA = _map(usRawChannelA, (float)0, (float)ADC_MAX_COUNT, (float)0, (float)ADC_MCP3202_REF_V);
  usRawChannelB = _map(usRawChannelB, (float)0, (float)ADC_MAX_COUNT, (float)0, (float)ADC_MCP3202_REF_V);

  /* muliply by the attentuation of the input stage VOLT_DIV_ATTENTUATION */
  usRawChannelA = usRawChannelA * VOLT_DIV_ATTENTUATION;
  usRawChannelB = usRawChannelB * VOLT_DIV_ATTENTUATION;

  fAbsoluteValue = usRawChannelA > usRawChannelB ? usRawChannelA - usRawChannelB : usRawChannelB - usRawChannelA;


  /* save to global ressource pointer */
  //ptRscStruct->voltageA = usRawChannelA;
  //ptRscStruct->voltageB = usRawChannelB;
  if(counter < AVERAGING_SAMPLES)
  {
    values_a = values_a + usRawChannelA;
    values_b = values_b + usRawChannelB;
    values_abs = values_abs + fAbsoluteValue;
    counter++;
    ptRscStruct->measurementDone = false;
  }
  else
  {
    ptRscStruct->voltageA = values_a / (float)AVERAGING_SAMPLES;
    values_a = 0;
    ptRscStruct->voltageB = values_b / (float)AVERAGING_SAMPLES;
    values_b = 0;
    ptRscStruct->absoluteVoltage = values_abs / (float)AVERAGING_SAMPLES;
    values_abs = 0;
    counter = 0;
    ptRscStruct->measurementDone = true;
  }

  /* get absolute value of substraction of input A and B */


  /* save absolute value to ressource pointer */
  //ptRscStruct->absoluteVoltage = fAbsoluteValue;
}

void update_ressources()
{
  switch(ptRscStruct->range)
  {
    case (uint8_t)RELAY_20mA_Mask:
      ptRscStruct->maximumCurrentInRange = MAX_CURR_20MA;
      break;
    case (uint8_t)RELAY_100mA_Mask:
      ptRscStruct->maximumCurrentInRange = MAX_CURR_100MA;
      break;
    case (uint8_t)RELAY_1000mA_Mask:
      ptRscStruct->maximumCurrentInRange = MAX_CURR_1000MA;
      break;
    case (uint8_t)RELAY_10000mA_Mask:
      ptRscStruct->maximumCurrentInRange = MAX_CURR_10000MA;
      break;
  }
}

void update_outputs()
{
  if(ptRscStruct->measurementDone)
  {
    /* update relay state via pcf8574 */
    if(IO_Expander.valueOut() != ptRscStruct->range)
    {
      /* reset output current to 0 in case of range change */
      ptRscStruct->setCurrent = 0;
      setDACOutput(DAC_MCP4821_GAIN_2, true, _map(ptRscStruct->setCurrent, 0.0, ptRscStruct->maximumCurrentInRange, 0.0, (float)DAC_MAX_COUNT));
      IO_Expander.write8(ptRscStruct->range);
    }
    /* update dac output */
    setDACOutput(DAC_MCP4821_GAIN_2, true, _map(ptRscStruct->setCurrent, 0.0, ptRscStruct->maximumCurrentInRange, 0.0, (float)DAC_MAX_COUNT));
  }
}

void loop()
{
  static int temp = 0;

#ifdef __SCPI__
  if(ptRscStruct->measurementDone)
  {
    /* process scpi commands */
    SCPI.ProcessInput(Serial, "\n");
  }
#endif

  /* update ressource pointer */
  update_ressources();

  /* process temperature reading from reference voltage */
  read_temperature();

  /* read analog voltage A & B and convert raw to voltage */
  read_input_voltage();

  /* process debouncing of range up/down buttons */
  RangeUpButton.process(millis());
  RangeDownButton.process(millis());


  /* actiavte dac output */
  PORTB |= DAC_MCP4821_SHDN_Mask;

  /* update outputs */
  update_outputs();

}

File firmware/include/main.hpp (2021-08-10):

#include "Arduino.h"


#define VERSION_STRING          "v0.1"
#define BAUD_RATE               115200

/* set debounce delay to 20ms */
#define BUTTON_DEBOUNCE_DELAY   20

/* range up & range down button pins */
#define BUTTON_RANGE_UP_PIN     4
#define BUTTON_RANGE_DOWN_PIN   5

/* self test verification borders */
#define MAX_DAC_OUT_DIFFERENCE  0.007  /* in decimal percent points 0.7%  */
#define ARDUINO_MAX_ADC_IN      0x3FF
#define ARDUINO_REF_VOLTAGE     5.000
#define TEMP_R_FEEDBACK         388.0
#define TEMP_R_IN               99.0
#define TEMP_REF_TEMP_COEF      1.96  /* 1.96mV / °C */
#define TEMP_REF_BASE_TEMP      25.0  /* °C */
#define TEMP_REF_BASE_MVOLT     550   /* mV at TEMP_REF_BASE_TEMP */
#define DIGITS_TO_SHOW          4
#define AVERAGING_SAMPLES       50  /* standard averaging samples */

/* maximum current ratings per range in mA */
#define MAX_CURR_20MA           ((float)20.0)
#define MAX_CURR_100MA          ((float)100.0)
#define MAX_CURR_1000MA         ((float)1000.0)
#define MAX_CURR_10000MA        ((float)10000.0)

/* self test adc inputs */
#define DAC_OUT_READBACK        A1
#define DAC_OUT_FS_READBACK     A2
#define TEMP_REFERENCE_VOLT_PIN A3

/* MCP3202 Defines */
#define ADC_MCP3202_CS          8
#define ADC_MCP3202_REF_V       5.000 /* from ref02cp */
#define ADC_CHANNEL_SENSE_A     0
#define ADC_CHANNEL_SENSE_B     1
#define VOLT_DIV_ATTENTUATION   8
#define DAC_MCP3202_BITs        12
#define ADC_MAX_COUNT           (pow(2, DAC_MCP3202_BITs) -1)

/* MCP4821 Defines */
#define DAC_MCP4821_CS_Offset   2
#define DAC_MCP4821_CS_Mask     (1 << DAC_MCP4821_CS_Offset)
#define DAC_MCP4821_SHDN_Offset 1
#define DAC_MCP4821_SHDN_Mask   (1 << DAC_MCP4821_SHDN_Offset)
#define DAC_MCP4821_GAIN_1      0x1
#define DAC_MCP4821_GAIN_2      0x0
#define DAC_MCP4821_BITs        12
#define DAC_REAL_FS_OUT         5.000
#define DAC_MAX_COUNT           (pow(2, DAC_MCP4821_BITs) -1)
#define DAC_MAX_VAL             (DAC_MAX_COUNT/1000)
/* tolerance values for upper and lower limit at self test */
#define DAC_MAX_TOL_VAL         DAC_MAX_VAL + (DAC_MAX_VAL * MAX_DAC_OUT_DIFFERENCE)
#define DAC_MIN_TOL_VAL         DAC_MAX_VAL - (DAC_MAX_VAL * MAX_DAC_OUT_DIFFERENCE)
#define DAC_FS_MAX_TOL_VAL      DAC_REAL_FS_OUT + (DAC_REAL_FS_OUT * MAX_DAC_OUT_DIFFERENCE)
#define DAC_FS_MIN_TOL_VAL      DAC_REAL_FS_OUT - (DAC_REAL_FS_OUT * MAX_DAC_OUT_DIFFERENCE)

/* PCF8574 Defines */
#define PCF8574_ADDRESS_A0      0
#define PCF8574_ADDRESS_A1      0
#define PCF8574_ADDRESS_A2      0
#define PCF8574_BASE_ADDRESS    0x20
#define PCF8574_ADDRESS         PCF8574_BASE_ADDRESS | (PCF8574_ADDRESS_A0 | (PCF8574_ADDRESS_A1 << 1) | (PCF8574_ADDRESS_A2 << 2))
#define RELAY_20mA_Offset       0
#define RELAY_20mA_Mask         ~(1 << RELAY_20mA_Offset)
#define RELAY_100mA_Offset      1
#define RELAY_100mA_Mask        ~(1 << RELAY_100mA_Offset)
#define RELAY_1000mA_Offset     2
#define RELAY_1000mA_Mask       ~(1 << RELAY_1000mA_Offset)
#define RELAY_10000mA_Offset    3
#define RELAY_10000mA_Mask      ~(1 << RELAY_10000mA_Offset)

/* ERROR Defines */
#define ERROR_I2C_Offset        0
#define ERROR_I2C_Mask          (1 << ERROR_I2C_Offset)
#define ERROR_DAC_OUT_Offset    1
#define ERROR_DAC_OUT_Mask      (1 << ERROR_DAC_OUT_Offset)
#define ERROR_DAC_OUT_FS_Offset 2
#define ERROR_DAC_OUT_FS_Mask   (1 << ERROR_DAC_OUT_FS_Offset)
#define ERROR_SCPI_PARAM_Offset 3
#define ERROR_SCPI_PARAM_Mask   (1 << ERROR_SCPI_PARAM_Offset)


/* SCPI Commands */
#define SCPI_IDENTIFY_CMD       F("*IDN?")
#define SCPI_ERROR_READ_CMD     F("*ERR?")
#define SCPI_SELF_TEST_CMD      F("*TEST?")
#define SCPI_RANGE_CMD_REQ      F("*RANGE?")
#define SCPI_RANGE_20mA         F("RANGE:20MA")
#define SCPI_RANGE_100mA        F("RANGE:100MA")
#define SCPI_RANGE_1000mA       F("RANGE:1A")
#define SCPI_RANGE_10000mA      F("RANGE:10A")
#define SCPI_TEMP_INTERNAL      F("TEMP:INTernal?")   /* query for internal temprature */
#define SCPI_TEMP_MOSFET        F("TEMP:MOSfet?")     /* query for tempretaure at high side mosfet */
#define SCPI_TEMP_REF           F("TEMP:REFerence?")  /* query for tempretaure at reference voltage */
#define SCPI_VOLT_SENSE_A       F("VOLT:A?")
#define SCPI_VOLT_SENSE_B       F("VOLT:B?")
#define SCPI_VOLT_ABSOLUTE      F("VOLT:ABS?")
#define SCPI_CURR_SET           F("CURR:SET")
#define SCPI_CURR_GET           F("CURR:GET?")

/* MCP4821 Command Struct */
typedef struct {
uint16_t value : DAC_MCP4821_BITs;
  unsigned int shdn : 1;
  unsigned int gain : 1;
} MCP4821_COMMAND_T;

/* global ressource structure */
typedef struct {
  uint8_t range;        /* active range consisting of RELAY_10000mA_Mask etc... */
  uint16_t gusError;    /* global error "short" */
  double mosfetTemp;    /* tempreature at FET */
  double referenceTemp;
  double atmelTemp;
  float voltageA;
  float voltageB;
  float absoluteVoltage;
  float setCurrent;
  float maximumCurrentInRange;
  bool measurementDone;
} RSC_STRUCT_T;

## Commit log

2021-07-05 * initial commit
    [const_curr_measure.kicad_pcb, const_curr_measure.sch]
2021-07-05 * most pcb routing
    [const_curr_measure.kicad_pcb, const_curr_measure.sch]
2021-07-06 * nearly finished pcb, changed front pcb connector to one big * added output enable switch net
    [const_curr_measure-B_Cu.gbl, const_curr_measure-B_Mask.gbs, const_curr_measure-B_Paste.gbp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]
2021-07-06 * first revision will order this version
    [const_curr_measure-B_Cu.gbl, const_curr_measure-B_Mask.gbs, const_curr_measure-B_Paste.gbp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]
2021-07-28 * addded Ibom * added normal bom
    [const_curr_measure.csv, const_curr_measure.kicad_pcb, const_curr_measure.sch]
2021-08-03 * initial commit of "firmware"
    [const_curr_measure.kicad_pcb, const_curr_measure.sch]
